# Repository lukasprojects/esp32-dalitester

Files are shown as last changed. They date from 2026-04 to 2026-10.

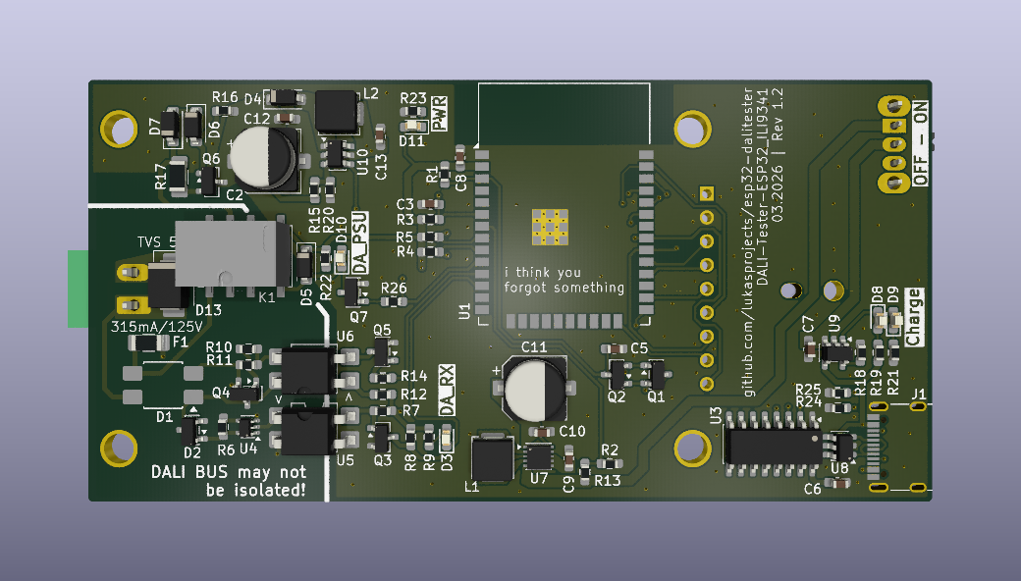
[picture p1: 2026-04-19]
ESP32_DALITester_front.png

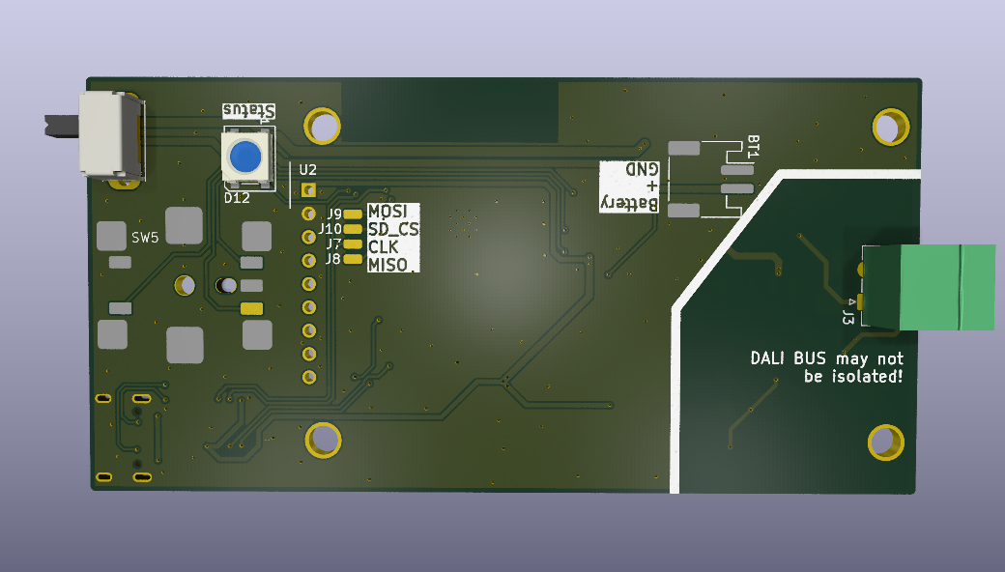
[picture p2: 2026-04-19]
ESP32_DALITester_back.png

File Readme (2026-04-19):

# ESP32 DALI Tester (TFT UI + Encoder + Bus Monitor)

A compact, hands-on DALI tool built around an ESP32 with a 2.2" ILI9341 TFT and a rotary encoder. It can send DALI commands, scan devices, commission / change short addresses, 
clone key configuration values, reset device config, and monitor bus traffic.

> Note on provenance:  
> The firmware was created using AI-assisted “vibe coding” (with human iteration and testing).  
> The PCB / hardware wiring & integration were designed and built by hand.
> Current FW version (1.3.8) only allows for DALI1 and a few DALI2 devices (not all sensors are found).
> Please understand that the DALI bus may not be isolated from mains voltage! Do not use the internal power supply if there is allready voltage on the bus!
  If you are using the internal power supply, the DALI bus is not fully isolated! If you use an external supply, the tool is fully isolated.
  The internal power supply should be able to output 150mA, so it is not capable to supply a whole set of 64 devices, i tested it with more than 10 devices.

---

# Features

- TFT UI (ILI9341, 320×240) with header/footer and a scrollable home menu
- Rotary encoder navigation
  - Rotate: navigate lists / change values
  - Short click: select / execute
  - Long press (≥ 700 ms): back
  - Looong press (≥ 8000 ms): easteregg
- DALI Master (via `qqqlab/DALI-Lighting-Interface` / `qqqDALI`)
  - Send common commands (ON/OFF/MIN/MAX)
  - Query status, levels, device type
- Commissioning / addressing
  - Commission all devices
  - Commission unaddressed devices
  - Change short address (initialize → program → verify → terminate)
- Clone configuration
  - Capture and apply: max/min level, power-on level, system-failure level, fade time, fade rate
- Reset config (treats NO_REPLY as success, useful for some drivers)
- Bus Monitor
  - Displays decoded forward frames (address+data) and backward replies
  - Live mode + freeze/scroll mode

---

# Hardware

Core components
- ESP32 (DevKit style)
- ILI9341 2.2" SPI TFT (Adafruit compatible)
- Rotary encoder with push button
- DALI interface hardware (tested with Waveshare Pico-DALI2 and a Tridonic DALI USB “mouse” for generating traffic)
                           
---

# Firmware / Libraries

- Arduino framework on ESP32
- Display:
  - `Adafruit_GFX`
  - `Adafruit_ILI9341`
- DALI:
  - `qqqlab/DALI-Lighting-Interface` (`qqqDALI`)

The DALI timing is driven by a periodic ESP32 hardware timer ISR calling `dali.timer()`.

---

# Building

PlatformIO
1. Install VS Code + PlatformIO
2. Clone this repository
3. Open the folder in VS Code
4. Build and upload:
   - `PlatformIO: Build`
   - `PlatformIO: Upload`
5. Monitor serial output:
   - `PlatformIO: Monitor` (115200 baud)

---

# Project Status

This is an actively iterated DIY project. Expect occasional breaking changes while improving UI, decoding, or hardware compatibility.

---

# Contributing

Issues and PRs are welcome — especially for:
- Additional command decoding in the bus monitor
- Compatibility notes for more DALI interface boards
- UI improvements without increasing RAM usage

---

# License

Please check the repository for the license file(s).  
This project depends on third-party libraries which come with their own licenses (notably the `qqqDALI` library).

---

# Credits

- `qqqlab/DALI-Lighting-Interface` (`qqqDALI`) for the DALI stack
- Adafruit GFX + ILI9341 libraries for the display layer

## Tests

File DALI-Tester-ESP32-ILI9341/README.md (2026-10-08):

# DALI Tester - ESP32 + ILI9341

Ein DALI (Digital Addressable Lighting Interface) Tester mit ESP32 Mikrocontroller, ILI9341 TFT-Display und Rotary Encoder Bedienung.

---

> **🤖 AI-Assistent:** Diese README.md sowie [TODO.md](TODO.md) sind bei jeder Änderung aktuell zu halten!
> Siehe TODO.md für detaillierte Anweisungen.

---

## Projektübersicht

| Eigenschaft | Wert |
|---|---|
| **Plattform** | ESP32 (espressif32) |
| **Framework** | Arduino |
| **Display** | ILI9341 2.8" SPI TFT (320x240) |
| **Eingabe** | Rotary Encoder mit Taster |
| **DALI Library** | qqqDALI (qqqlab) |
| **Version** | 1.4.0 |
| **Letztes Update** | 2026-07-30 |

## Funktionen

### Implementierte Features

| Feature | Status | Beschreibung |
|---|---|---|
| Home Menu | ✅ | Scrollbares Kachel-Menü (3×4 Grid) mit Icons |
| Scan Devices | ✅ | Scannt Control Gear (SA 0-63), DALI-2 Control Devices und unadressierte Geräte |
| Device Info | ✅ | Kontextmenü mit Seriennummer, Typ und Locate |
| Device Parameters | ✅ | Alle Parameter anzeigen/bearbeiten inkl. Gruppen & Szenen |
| Broadcast Control | ✅ | Drehen=Dimmen, Click=AN/AUS |
| Address Device | ✅ | Address ALL, Unaddressed, Change Address |
| Clone Config | ✅ | Liest/schreibt Gerätekonfiguration |
| Reset Device | ✅ | Setzt Einzelgerät zurück (DALI RESET) |
| DALI PSU | ✅ | EXT/INT Umschaltung mit Confirm-Popup |
| Send CMD | ✅ | Broadcast/Group/Short + ON/OFF/MIN/MAX |
| Locate | ✅ | Zyklisches MIN/MAX Blinken |
| Bus Monitor | ✅ | Frame-Anzeige mit Freeze/Live Mode, DALI-2 Device-Cmd Erkennung |
| SD Browser | ✅ | Ordnerstruktur der SD-Karte direkt auf dem TFT durchblättern |
| WAGO Viewer | ✅ | Read-only Anzeige von WAGO-Projekten aus entpackten XML-Dateien |

### UI Features

- **Header**: Titel + Status-Badges (BUS Status, PSU Mode)
- **Footer**: Kontext-sensitiver Hint-Text
- **Navigation**: Rotate=Auswahl, Click=Bestätigen, Long Press (≥700ms)=Zurück

## Hardware-Konfiguration

### Pin-Belegung (Hardware Rev1.1)

| Funktion | Pin | Beschreibung |
|---|-----|---|
| **TFT Display** | | |
| TFT_CS | GPIO 5 | Chip Select |
| TFT_DC | GPIO 4 | Data/Command |
| TFT_RST | GPIO 17 | Reset (-1 wenn an EN) |
| TFT_MOSI | GPIO 23 | SPI MOSI (VSPI) |
| TFT_SCLK | GPIO 18 | SPI Clock (VSPI) |
| TFT_MISO | GPIO 19 | SPI MISO (optional) |
| TFT_LED | GPIO 2 | Backlight (HIGH = an) |
| **Encoder** | | |
| ENC_A | GPIO 33 | Encoder Signal A |
| ENC_B | GPIO 32 | Encoder Signal B |
| ENC_BTN | GPIO 34 | Button (active LOW, ext. Pullup) |
| **DALI Interface** | | |
| DALI_TX | GPIO 26 | Transmit (Open-Drain) |
| DALI_RX | GPIO 27 | Receive |
| DALI_PSU_EN | GPIO 25 | PSU Enable |
| **Battery Monitor** | | |
| BATTERY_ADC | GPIO 35 | Akkuspannung via Spannungsteiler |
| **SD Card** | | |
| SD_CS | GPIO 13 | Chip Select der SD-Karte (SPI shared mit TFT) |

### Konfigurierbare Einstellungen

Alle Pins und Settings können in `include/config.h` angepasst werden:

```cpp
// TX/RX Invertierung (abhängig von Hardware-Interface)
#define DALI_TX_INVERT  true    // true für typische Opto/Transistor-Schaltung
#define DALI_RX_INVERT  false   // true wenn RX-Schaltung invertiert

// PSU Enable Logik
#define PSU_EN_ACTIVE_HIGH  true  // HIGH = PSU aktiv

// Encoder Richtung und Steps
#define ENCODER_DIR     -1      // +1 oder -1 für Umkehrung
#define ENC_STEP_DIV    4       // Steps pro Rastung

// SD-Karte (shared SPI mit TFT)
#define SD_CS           13
```

## SD Browser und WAGO Viewer

- **SD Browser**: zeigt die Ordnerstruktur der eingelegten SD-Karte direkt im Gerät an.
- **WAGO Viewer**: sucht auf der SD-Karte nach WAGO-Projekten und zeigt die projektierten XML-Dateien read-only an.
- **Wichtig**: Für die eigentliche Projektansicht muss eine `.wdc2s` Datei am PC entpackt und als XML-Ordner auf die SD-Karte kopiert werden. Gepackte `.wdc2s` Dateien werden erkannt, aber aktuell nur mit einem Hinweis angezeigt.

## Projektstruktur

```
DALI-Tester-ESP32-ILI9341/
├── platformio.ini          # PlatformIO Konfiguration
├── README.md               # Diese Datei
├── include/
│   ├── config.h            # Pin-Definitionen und Settings
│   ├── dali/
│   │   └── dali_interface.h    # DALI API Header
│   └── ui/
│       ├── ui.h            # UI Core Header
│       └── screens.h       # Screen Handler Header
├── src/
│   ├── main.cpp            # Hauptprogramm
│   ├── dali/
│   │   └── dali_interface.cpp  # DALI Implementierung
│   └── ui/
│       ├── ui.cpp          # UI Core Implementierung
│       └── screens.cpp     # Alle Screen Handler
├── lib/                    # (leer - Libraries via lib_deps)
└── test/                   # (leer - für Unit Tests)
```

## Build & Flash Anleitung

### Voraussetzungen

- [PlatformIO](https://platformio.org/) (VS Code Extension oder CLI)
- USB-Kabel für ESP32

### Build

```bash
# Projekt bauen
pio run

# Oder mit Verbose Output
pio run -v
```

### Flash

```bash
# Firmware hochladen
pio run -t upload

# Mit spezifischem Port
pio run -t upload --upload-port COM3
```

### Serial Monitor

```bash
# Monitor starten (115200 baud)
pio device monitor -b 115200

# Build + Upload + Monitor
pio run -t upload -t monitor
```

## Dependencies

Die Libraries werden automatisch über `lib_deps` in `platformio.ini` installiert:

```ini
lib_deps = 
    adafruit/Adafruit GFX Library@^1.11.9
    adafruit/Adafruit ILI9341@^1.6.0
    adafruit/Adafruit BusIO@^1.14.5
    https://github.com/qqqlab/DALI-Lighting-Interface.git
```

## DALI Interface Hardware

### Typischer Schaltkreis

```
ESP32 DALI_TX (GPIO26) ──[1k]──┬── Optokoppler/Transistor ── DALI Bus +
                               │
                              GND

DALI Bus + ── Optokoppler RX ──┬── DALI_RX (GPIO27)
                               │
                             [10k]
                               │
                              3.3V
```

**Hinweise:**
- TX Pin als Open-Drain konfiguriert
- TX_INVERT=true für typische Transistor/Opto-Schaltungen
- RX mit Pullup (intern oder extern)
- DALI Bus benötigt 16V DC Versorgung

## Bus Monitor

Der Bus Monitor nutzt **ausschließlich** `dali.rx()` aus der qqqDALI Library - **kein RMT** (wegen Manchester Alignment Problemen).

### Frame-Dekodierung

| Frame Typ | Format | Beispiel |
|---|---|---|
| Broadcast Cmd | `BC <CMD>` | `BC MAX` |
| Group Cmd | `G<n> <CMD>` | `G5 OFF` |
| Short Addr Cmd | `SA<n> <CMD>` | `SA12 Q_STATUS` |
| Direct Arc | `SA<n> ARC <val>` | `SA0 ARC 128` |
| Reply | `REPLY 0x<hex> (<dec>)` | `REPLY 0x80 (128)` |

## Bedienung

### Encoder

| Aktion | Funktion |
|---|---|
| Drehen | Navigation / Wert ändern |
| Kurz drücken (<700ms) | Select / Next / Execute |
| Lang drücken (≥700ms) | Zurück / Abbrechen |

### Status Badges

| Badge | Bedeutung |
|---|---|
| IDLE | Keine Aktivität |
| ACT | RX Aktivität erkannt |
| SEND | Kommando wird gesendet |
| OK | Letztes Kommando erfolgreich |
| NO RPLY | Keine Antwort erhalten |
| BUS ERR | DALI Bus Fehler |
| FAILED | Kommando fehlgeschlagen |
| EXT | Externe PSU |
| INT | Interne PSU aktiv |

## Changelog

### Version 1.4.0 (2026-07-30)

- ✅ **SD Browser**: Neuer Menüpunkt zum Durchblättern der SD-Karten-Ordnerstruktur direkt auf dem TFT
- ✅ **WAGO Viewer**: Neuer Menüpunkt für read-only Anzeige von WAGO-Projekten auf Basis entpackter `solution.xml` / `module_*.xml` Dateien
- ✅ **SD-Konfiguration**: Neue `SD_CS` / `SD_SPI_*` Defines in `include/config.h` für anpassbare Verdrahtung

### Version 1.3.8 (2026-04-12)

- ✅ **Easter Egg**: Pong-Spiel! Im Hauptmenü Encoder 8 Sekunden gedrückt halten. Wand links, Paddle rechts per Encoder. Long Press zum Verlassen.

### Version 1.3.7 (2026-04-12)

- ✅ **Home-Menü Flicker-Fix**: Partial Redraw zeichnet nur geänderte Tiles neu statt gesamten Content-Bereich
- ✅ **Header-Badges vergrößert**: Badges 4px höher und breiter für bessere Lesbarkeit
- ✅ **Batterie-Anzeige Fix**: Spannung wird jetzt sofort beim Start korrekt angezeigt (war 0.0V)

### Version 1.3.6 (2026-04-08)

- ✅ **Hardware Rev 1.1**: Pin-Belegung aktualisiert (TFT_CS=GPIO5, TFT_DC=GPIO4, TFT_RST=GPIO17)
- ✅ **LCD Backlight**: Neuer TFT_LED Pin (GPIO 2) für Hintergrundbeleuchtung, dauerhaft HIGH
- ✅ **Build-Fix**: `-Wno-error=return-type` Flag für Kompatibilität mit aktualisierter ESP32-Plattform

### Version 1.3.5 (2026-03-25)

- ✅ **GOTO SCENE im Send CMD**: Szenen 0-15 können jetzt direkt über Send CMD aufgerufen werden (neues Kommando "SCENE" mit Szenen-Nummer Auswahl)
- ✅ **HW-Version & Credits im Home-Screen**: Footer zeigt jetzt zweizeilig FW-Version (by Claude Code Opus 4.6) und HW-Version (by Lukas Meissner)
- ✅ **HW_VERSION Define**: Zentrale HW-Versionsverwaltung in config.h

### Version 1.3.4 (2026-03-24)

- ✅ **Bugfix Bus Monitor Live-Ansicht**: Ring-Buffer verwendete nur Count für Änderungserkennung — bei vollem Buffer (80 Einträge) wurde kein Update mehr erkannt. Jetzt mit Generation-Counter der bei jedem neuen Frame zählt

### Version 1.3.3 (2026-03-22)

- ✅ **Bugfix Reset Adresse löschen**: SET SHORT ADDRESS wird jetzt mit REPEAT-Flag (doppelt) gesendet wie vom DALI-Standard gefordert
- ✅ **Bugfix DALI PSU Navigation**: Popup-Rückkehr stellt previousScreen korrekt wieder her, kein doppeltes Zurück mehr nötig
- ✅ **FW-Version im Home-Screen**: Footer zeigt Firmware-Version und "powered by Claude Opus"
- ✅ **FW_VERSION Define**: Zentrale Versionsverwaltung in config.h

### Version 1.3.2 (2026-03-22)

- ✅ **Scrollbares Kachel-Menü**: 3×4 Grid mit größeren Kacheln (102×88px), scrollbar per Encoder
- ✅ **Pixel-Art Icons**: 10 individuelle Icons für jedes Menü-Item (Lupe, Zahnrad, Blitz, Fadenkreuz, etc.)
- ✅ **Visuelle Verbesserung**: Ausgewählte Kachel in Cyan, unselektierte mit dezenter Umrandung und Icon

### Version 1.3.1 (2026-03-21)

- ✅ **Home Menu Kachel-Design**: 3×4 Grid mit abgerundeten Kacheln statt scrollbare Liste
- ✅ **Tile Labels**: Kompakte zweizeilige Beschriftung pro Kachel
- ✅ **Visuelle Verbesserung**: Ausgewählte Kachel in Cyan, unselektierte mit dezenter Umrandung

### Version 1.3.0 (2026-03-20)

- ✅ **DALI-2 Control Device Scan**: Sensoren, Taster und andere Control Devices werden per S=0 Adressierung erkannt
- ✅ **Unified Scan List**: Control Gear (weiss), Control Devices (grün) und Unadressierte (orange) in einer Liste
- ✅ **DALI-2 Device Type Namen**: Neue Typnamen für Device Types 128-140 (Switch, OccSensor, Gateway, etc.)
- ✅ **Bus Monitor DALI-2**: S=0 Frames mit Command-Werten >=0x90 werden als Device-Commands dekodiert

### Version 1.2.3 (2026-03-19)

- ✅ **Bugfix Adresse löschen**: INITIALISE/TERMINATE Sequenz hinzugefügt - SET SHORT ADDRESS erfordert INITIALISE-Status laut DALI-Standard
- ✅ **Bugfix Navigation**: Zurück von Detailansicht kehrt jetzt zur Scan-Liste zurück statt zum Home-Menü

### Version 1.2.2 (2026-03-20)

- ✅ **Scan Devices: Unified List**: Adressierte und unadressierte Geräte werden jetzt in einer gemeinsamen Liste angezeigt
- ✅ **Unadressierte Zählung**: `daliCountUnaddressed()` zählt unadressierte Geräte per Binary-Search (ohne Adressvergabe)
- ✅ **Visuelle Unterscheidung**: Unadressierte Geräte in Orange, adressierte in Weiß

### Version 1.2.1 (2026-03-19)

- ✅ **Bugfix Clone/Write Config**: Robusteres Schreiben mit Verifikation, damit fehlerhafte Write-Vorgaenge nicht mehr als OK angezeigt werden
- ✅ **Bugfix Fade Query**: Korrekte Auswertung von Fade Time/Fade Rate aus dem gemeinsamen DALI-Reply-Byte
- ✅ **Bugfix Reset Device**: Reset + optionales Adress-Loeschen mit korrekter DALI-Sequenz und Rueckpruefung
- ✅ **Hardware Rev1.0 Doku**: Pin-Tabelle in README an `include/config.h` angepasst

### Version 1.2.0 (2026-03-03)

- ✅ **Device Parameters**: Neues Menü zur Anzeige/Bearbeitung aller Geräteparameter
  - Max/Min Level, Power On Level, System Failure Level
  - Fade Time, Fade Rate
  - Gruppenzuweisungen (0-15) anzeigen und ändern
  - Szenen-Level (0-15) anzeigen und setzen
- ✅ **Bugfix Broadcast Control**: Display-Refresh beim Dimmen korrigiert
- ✅ **Bugfix Serial Number**: Bessere Anzeige bei nicht zugewiesenen Seriennummern ("Not Assigned")

### Version 1.1.0 (2026-02-24)

- ✅ **Broadcast Control**: Neues Menü zum direkten Dimmen aller Leuchten (Drehen=Dimmen, Click=AN/AUS)
- ✅ **Device Info Kontextmenü**: Klick auf gescannte Geräte zeigt Details (Seriennummer, Typ, Status)
- ✅ **Locate im Scan**: Locate-Funktion direkt aus dem Device Info Screen (2s Intervall)
- ✅ **Device Type Namen**: Anzeige von Typnamen statt Nummern (Fluorescent, LED, etc.)
- ✅ **Pin-Belegung aktualisiert**: TFT_CS=GPIO2, TFT_DC=GPIO17 für PCB v1

### Version 1.0.0 (2026-02-22)

- ✅ Initiale Implementierung
- ✅ Alle 8 Hauptmenü-Funktionen
- ✅ Encoder-Steuerung mit Debouncing
- ✅ DALI Master via qqqDALI
- ✅ Bus Monitor mit Ring-Buffer (80 Einträge)
- ✅ Scrollbare Listen
- ✅ Confirm-Popup für PSU

## Bekannte Einschränkungen

1. **Bus Monitor RX**: Erkennt aktuell nur 8-Bit Backward Frames vollständig. Forward Frame Dekodierung für passives Mithören erfordert erweiterte qqqDALI Integration.

2. **Commissioning**: Nutzt die qqqDALI `commission()` Funktion. Komplexe Szenarien (Multi-Device, Conflicts) müssen ggf. manuell behandelt werden.

3. **Display Refresh**: Bei schnellen Änderungen kann leichtes Flackern auftreten.

4. **WAGO Viewer**: Die Projektanzeige ist aktuell read-only und nutzt eine heuristische XML-Auswertung. Für volle Bearbeitung/Speicherung fehlt noch der spätere Import/Export-Schritt.

## Assumptions (Designentscheidungen)

1. **Timer**: ESP32 Hardware Timer 0 mit 80 Prescaler (1µs Auflösung) für DALI Timing (104µs Interrupt)

2. **Encoder**: Typischer Quadrature-Encoder mit 4 Steps pro Detent

3. **DALI Timing**: Standard Manchester-Encoding mit qqqDALI Library

4. **Ring Buffer**: Statische Allokation (80 Einträge) ohne dynamischen Speicher

5. **Screen State**: Separate State-Structs pro Screen (statisch alloziert)

## Lizenz

Dieses Projekt verwendet die qqqDALI Library von qqqlab (MIT License).

---

*Dokumentation zuletzt aktualisiert: 2026-07-30*

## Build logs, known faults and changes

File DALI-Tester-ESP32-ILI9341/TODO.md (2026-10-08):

# DALI Tester - Feature & Aufgabenliste

> **Letzte Aktualisierung:** 2026-07-30

---

## 🤖 AI-Assistent Hinweis

> **WICHTIG FÜR JEDE NEUE SESSION:**
> 
> 1. **TODO.md** - Diese Datei bei jeder Änderung aktualisieren:
>    - Erledigte Features mit `[x]` markieren
>    - Neue Features/Bugs hinzufügen
>    - "Nächste Schritte" Prioritäten anpassen
>    - "Letzte Aktualisierung" Datum aktualisieren
>
> 2. **README.md** - Bei relevanten Änderungen aktualisieren:
>    - Feature-Status-Tabelle pflegen
>    - Changelog erweitern bei neuen Versionen
>    - "Bekannte Einschränkungen" aktuell halten
>    - "Letztes Update" Datum im Header aktualisieren
>
> 3. **Projektstatus** - Immer den aktuellen Stand dokumentieren:
>    - Was funktioniert?
>    - Was ist in Arbeit?
>    - Was sind bekannte Probleme?
>
> So weiß jeder Nutzer (und jede AI-Session) sofort, wie der Projektstatus ist.
>
> 4. **Build & Test** - PlatformIO Befehle (PowerShell):
>    ```powershell
>    # Build
>    & "$env:USERPROFILE\.platformio\penv\Scripts\platformio.exe" run
>    
>    # Upload
>    & "$env:USERPROFILE\.platformio\penv\Scripts\platformio.exe" run --target upload
>    
>    # Serial Monitor
>    & "$env:USERPROFILE\.platformio\penv\Scripts\platformio.exe" device monitor -b 115200
>    ```
>    **Hinweis:** `pio` und `python -m platformio` funktionieren NICHT in dieser Umgebung!

---

## Legende

- ✅ Abgeschlossen
- 🔄 In Bearbeitung
- ⏳ Geplant (hohe Priorität)
- 💡 Idee / Nice-to-have
- ❌ Blockiert / Problem

---

## ⚠️ Erinnerung: FW-Version

> **Bei JEDEM Release:** `FW_VERSION` in `include/config.h` hochzählen!
> Auch `README.md` Versionstabelle und Changelog aktualisieren.

---

## Hauptfunktionen

### Home Menu
- [x] Scrollbares Kachel-Menü (3×4 Grid) mit Icons und abgerundeten Kacheln
- [x] 10 Bitmap-Icons (38×38px, 1-bit monochrom via drawBitmap)
- [x] Header mit Titel und Status-Badges
- [x] Footer mit kontext-sensitiven Hints
- [x] Menüpunkt für SD-Karten-Browser
- [x] Menüpunkt für WAGO-Projektanzeige (read-only)

### SD / Projektdateien
- [x] SD-Karten-Ordnerstruktur anzeigen
- [x] WAGO-Projekte auf SD erkennen (`solution.xml`, `module_*.xml`)
- [x] Read-only Anzeige von WAGO-Projekten
- [ ] WAGO-Projekte bearbeiten und speichern
- [ ] Native `.wdc2s` ZIP-Dateien direkt auf dem ESP32 lesen

### Device Parameters
- [x] Geräteparameter auslesen (Levels, Fade, etc.)
- [x] Gruppenzuweisungen anzeigen (bitmask)
- [x] Szenen-Level anzeigen (0-15)
- [x] Parameter bearbeiten und speichern
- [x] Gruppen hinzufügen/entfernen
- [x] Szenen-Level setzen

### Scan Devices
- [x] Scan Short Addresses 0-63
- [x] Device Type Anzeige
- [x] Scrollbare Ergebnisliste
- [x] Device Type Namen statt Nummern anzeigen
- [x] Zusätzliche Geräteinformationen (Actual Level, Status)
- [x] Geräte-Kontextmenü mit Seriennummer und Locate
- [x] Erkennung von nicht-adressierten Geräten auf dem Bus
- [x] Unadressierte Geräte in der Scan-Liste anzeigen (unified list)
- [x] DALI-2 Control Devices erkennen und in Scan-Liste anzeigen
- [x] Busspannungs-Erkennung vor Scan (Error Handling bei fehlendem Bus)

### Broadcast Control
- [x] Click = AN/AUS Toggle
- [x] Drehen = Dimmen (Direct Arc Power)
- [x] Visueller Level-Balken

### Address Device
- [x] Address ALL (alle Geräte neu adressieren)
- [x] Address Unaddressed (nur nicht-adressierte)
- [x] Change Address (einzelne Adresse ändern)
- [ ] Fortschrittsanzeige während Commissioning
- [ ] Konflikt-Erkennung bei doppelten Adressen

### Clone Config
- [x] Lesen der Gerätekonfiguration
- [x] Schreiben auf anderes Gerät
- [x] Source/Target Auswahl
- [ ] Config-Preview vor dem Schreiben
- [ ] Mehrere Geräte gleichzeitig beschreiben

### Reset Device
- [x] DALI RESET Befehl an einzelnes Gerät
- [ ] Reset ALL (Broadcast Reset)
- [ ] Reset-Bestätigung mit Abfrage

### DALI PSU
- [x] EXT/INT Umschaltung
- [x] Confirm-Popup vor Umschaltung
- [ ] PSU Status-Überwachung (Überstrom, etc.)

### Send CMD
- [x] Target-Typ: Broadcast / Group / Short Address
- [x] Kommandos: ON / OFF / MIN / MAX
- [ ] Erweiterte Kommandos (UP, DOWN, STEP_UP, STEP_DOWN)
- [x] Scene-Befehle (GOTO SCENE 0-15)
- [ ] Direct Arc Level senden (0-254)
- [ ] Query-Kommandos mit Antwort-Anzeige

### Locate
- [x] Zyklisches MIN/MAX Blinken
- [x] Einstellbares Intervall (200-3000ms)
- [x] Start/Stop Steuerung
- [ ] Locate für Gruppen
- [ ] Locate mit Fade statt hartem Umschalten

### Bus Monitor
- [x] Live Frame-Anzeige
- [x] Freeze/Live Mode Toggle
- [x] Ring-Buffer (80 Einträge)
- [x] Frame-Dekodierung (BC, Group, Short)
- [x] DALI-2 Event Frames (24-bit) Dekodierung
- [ ] Frame-Filter (nur bestimmte Adressen)
- [ ] Export/Log-Funktion
- [ ] Timestamp-Anzeige (relativ oder absolut)

---

## UI / UX

### Display
- [x] ILI9341 320x240 TFT Support
- [x] Farbschema (Dark Theme)
- [x] LCD Backlight Steuerung (TFT_LED Pin)
- [ ] Helligkeit einstellbar
- [ ] Display-Timeout / Screensaver
- [ ] Alternative Farbschemata

### Navigation
- [x] Rotary Encoder mit Taster
- [x] Long Press (≥700ms) für Zurück
- [x] Debouncing
- [ ] Beschleunigtes Scrollen bei schnellem Drehen
- [ ] Haptic Feedback (optional, falls Hardware vorhanden)

### Status-Anzeige
- [x] BUS Status Badge (IDLE, ACT, SEND, OK, etc.)
- [x] PSU Mode Badge (EXT/INT)
- [x] Batterie-Anzeige im Header (Prozent + Farbe)
- [ ] Verbindungsstatus-Indikator
- [ ] Fehler-Log / History

---

## DALI Protokoll

### Basis-Kommandos
- [x] Direct Arc Power Control
- [x] OFF, RECALL MAX, RECALL MIN
- [x] Query Status, Query Actual Level
- [ ] UP, DOWN, STEP UP, STEP DOWN
- [ ] ON AND STEP UP, STEP DOWN AND OFF

### Konfiguration
- [x] Query/Set Max Level
- [x] Query/Set Min Level
- [x] Query/Set Power On Level
- [x] Query/Set System Failure Level
- [x] Query/Set Fade Time/Rate
- [ ] Query/Set Extended Fade Time
- [ ] Scene Level Konfiguration (0-15)

### Gruppen
- [x] Gruppe zuweisen (ADD TO GROUP) via Device Parameters
- [x] Gruppe entfernen (REMOVE FROM GROUP) via Device Parameters
- [x] Gruppenübersicht anzeigen

### Erweiterte Features
- [ ] DALI-2 Control Device Discovery (Sensoren, Taster)
- [x] DALI-2 Device Type Unterstützung (Control Device Scan + Typ-Namen)
- [ ] Memory Bank Lesen
- [ ] Colour Control (DT8)
- [x] Event-basierte Anzeige (Bus Monitor)

---

## Hardware / System

### ESP32
- [x] Hardware Timer für DALI Timing (104µs)
- [x] Open-Drain TX Pin
- [ ] Deep Sleep Mode bei Inaktivität
- [ ] OTA Updates
- [ ] WiFi-Interface (optional)

### DALI Interface
- [x] TX/RX Invertierung konfigurierbar
- [x] PSU Enable Steuerung
- [ ] Bus-Spannungsüberwachung
- [ ] Kurzschluss-Erkennung

---

## Bekannte Probleme

- [ ] **Bus Monitor**: Forward Frames (16-bit) werden nicht vollständig dekodiert bei passivem Mithören
- [ ] **Display Flackern**: Bei schnellen Änderungen kann leichtes Flackern auftreten
- [ ] **Commissioning**: Komplexe Multi-Device Szenarien erfordern manuelle Behandlung

---

## Nächste Schritte (Priorisiert)

1. ✅ Forward Frame Dekodierung im Bus Monitor (erledigt inkl. DALI-2 Events)
2. ⏳ Erweiterte Send CMD Optionen (UP, DOWN, Direct Arc)
3. ✅ Device Type Namen statt Nummern (erledigt)
4. ⏳ Query-Kommandos mit Antwort-Anzeige
5. ✅ Gruppen-Management (erledigt via Device Parameters)
6. ✅ Scene-Konfiguration (erledigt via Device Parameters)
7. ✅ Erkennung nicht-adressierter Geräte (erledigt im Scan)
8. ✅ DALI-2 Control Device Scan (Sensoren, Taster etc.)
9. 💡 DALI-2 Control Device Discovery (erweitert: Instanzen, Memory Banks)
10. ⏳ WAGO-Projekte bearbeiten und wieder speichern
11. 💡 WiFi-Interface für Remote-Steuerung

---

## Notizen

- 2026-03-19: Clone/Config-Write und Reset-Sequenzen robuster gemacht (inkl. Verifikation und korrektem Adress-Loeschen via SET SHORT ADDRESS + DTR=255).
- 2026-03-19: README Pin-Mapping auf aktuelle Hardware Rev1.0 aus `include/config.h` abgeglichen.
- 2026-03-20: Scan Devices zeigt jetzt adressierte UND unadressierte Geräte in einer gemeinsamen Liste (v1.2.2).
- 2026-03-19: Adress-Löschung korrigiert (INITIALISE fehlte), Navigation von Detailansicht geht zurück zur Scan-Liste (v1.2.3).
- 2026-04-12: Pong Easter Egg hinzugefügt (8s Hold im Home-Menü) (v1.3.8).
- 2026-07-30: SD Browser und read-only WAGO Viewer hinzugefügt. WAGO-Projekte werden auf SD per `solution.xml` / `module_*.xml` erkannt; gepackte `.wdc2s` Dateien zeigen vorerst nur einen Entpack-Hinweis (v1.4.0).
- 2026-04-12: Home-Menü Partial Redraw (nur geänderte Tiles), Header-Badges vergrößert (+4px), Batterie-Anzeige beim Start repariert (v1.3.7).
- 2026-04-08: Hardware Rev 1.1 - Pin-Belegung aktualisiert (TFT_CS=5, TFT_DC=4, TFT_RST=17), LCD Backlight Pin (TFT_LED=GPIO2) hinzugefügt.
- 2026-03-24: Bus Monitor Live-Ansicht repariert - Ring-Buffer Count blieb bei 80 stehen, Generation-Counter eingeführt (v1.3.4).
- 2026-03-22: Reset-Adressloeschung repariert (SET SHORT ADDRESS ohne REPEAT Flag war Ursache), PSU-Popup Navigation repariert, FW-Version im Home-Footer (v1.3.3).

<!-- 
Platz für eigene Notizen, Ideen, etc.
-->

---

*Diese Datei wird laufend aktualisiert. Features können nach Bedarf umpriorisiert werden.*

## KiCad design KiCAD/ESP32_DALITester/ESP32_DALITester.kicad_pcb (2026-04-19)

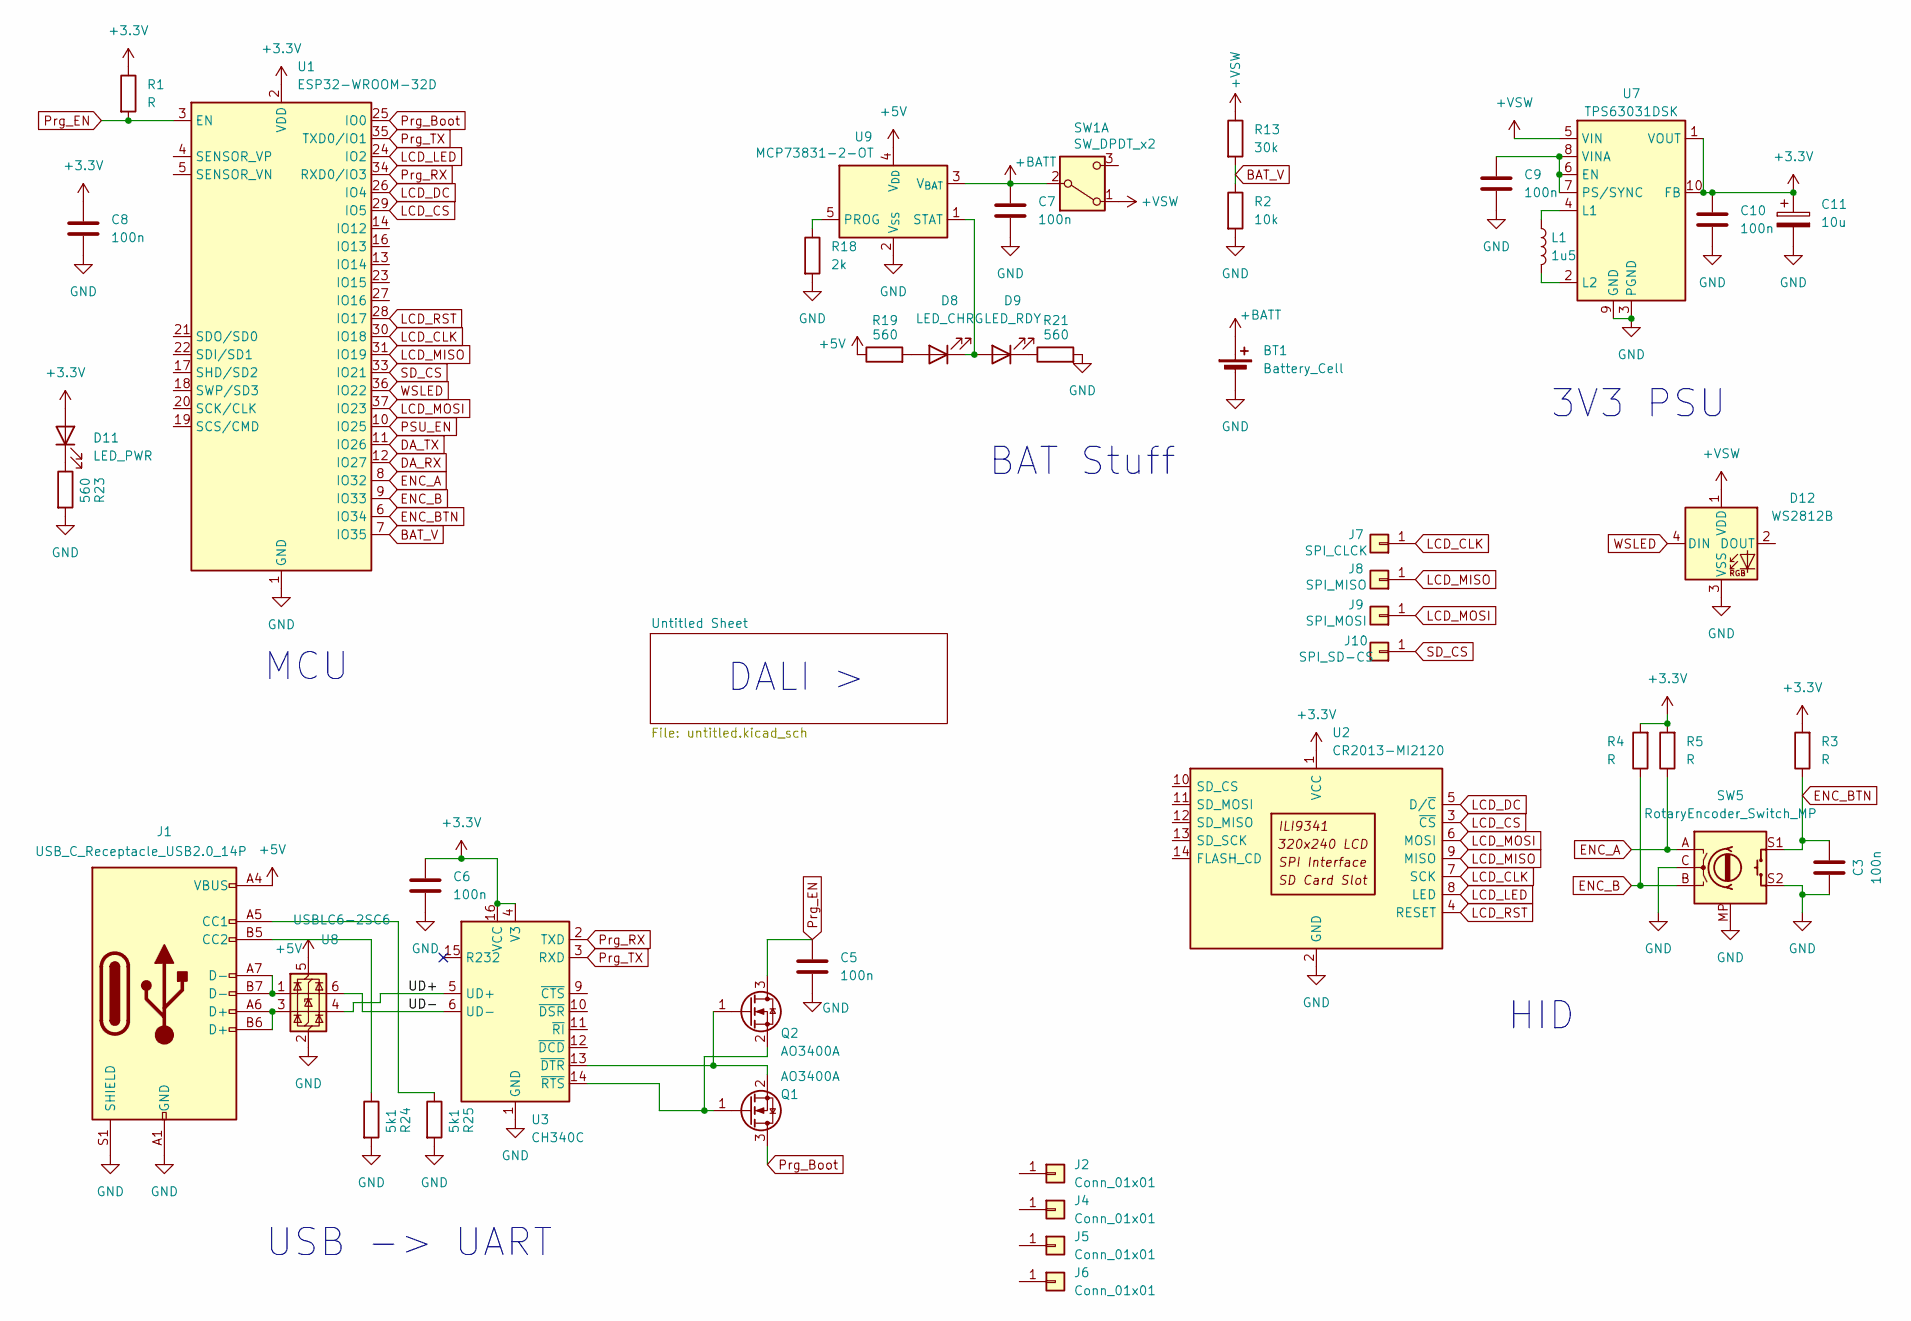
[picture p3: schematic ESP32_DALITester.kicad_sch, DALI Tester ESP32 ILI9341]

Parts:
BT1: Battery_Cell; JST_PH_S2B-PH-SM4-TB_1x02-1MP_P2.00mm_Horizontal
C3, C5, C6, C7, C8, C9, C10: 100n; C_0603_1608Metric_Pad1.08x0.95mm_HandSolder
C11: 10u; CP_Elec_6.3x3
D8: LED_CHRG; LED_0603_1608Metric_Pad1.05x0.95mm_HandSolder
D9: LED_RDY; LED_0603_1608Metric_Pad1.05x0.95mm_HandSolder
D11: LED_PWR; LED_0603_1608Metric_Pad1.05x0.95mm_HandSolder
D12: WS2812B; LED_WS2812B_PLCC4_5.0x5.0mm_P3.2mm
J1: USB_C_Receptacle_USB2.0_14P; USB_C_Receptacle_G-Switch_GT-USB-7010ASV
J2, J4, J5, J6: Conn_01x01; MountingHole_3mm
J7: SPI_CLCK; SolderWirePad_1x01_SMD_1x2mm
J8: SPI_MISO; SolderWirePad_1x01_SMD_1x2mm
J9: SPI_MOSI; SolderWirePad_1x01_SMD_1x2mm
J10: SPI_SD-CS; SolderWirePad_1x01_SMD_1x2mm
L1: 1u5; L_APV_APH0420
Q1, Q2: AO3400A; SOT-23
R1, R3, R4, R5: R; R_0603_1608Metric_Pad0.98x0.95mm_HandSolder
R2: 10k; R_0603_1608Metric_Pad0.98x0.95mm_HandSolder
R13: 30k; R_0603_1608Metric_Pad0.98x0.95mm_HandSolder
R18: 2k; R_0603_1608Metric_Pad0.98x0.95mm_HandSolder
R19, R21, R23: 560; R_0603_1608Metric_Pad0.98x0.95mm_HandSolder
R24, R25: 5k1; R_0603_1608Metric_Pad0.98x0.95mm_HandSolder
SW1: SW_DPDT_x2; SW_Slide_SPDT_Angled_CK_OS102011MA1Q
SW5: RotaryEncoder_Switch_MP; BOURNS PEC11J-9220F-H0015
U1: ESP32-WROOM-32D
U2: CR2013-MI2120
U3: CH340C; SOIC-16_3.9x9.9mm_P1.27mm
U7: TPS63031DSK; WSON-10-1EP_2.5x2.5mm_P0.5mm_EP1.2x2mm
U8: USBLC6-2SC6; SOT-23-6
U9: MCP73831-2-OT; SOT-23-5

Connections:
+3.3V: C6.1, C8.1, C10.1, C11.1, D11.2 (A), R1.1, R3.2, R4.2, R5.2, U1.2 (VDD), U2.1 (VCC), U3.4 (V3), U3.16 (VCC), U7.1 (VOUT), U7.10 (FB); also elsewhere on the board
+5V: J1.A4 (VBUS), J1.A9 (VBUS), J1.B4 (VBUS), J1.B9 (VBUS), R19.1, U8.5 (VBUS), U9.4 (V_{DD})
+BATT: BT1.2 (+), C7.1, SW1.2 (B), U9.3 (V_{BAT})
+VSW: D12.1 (VDD), R13.1, SW1.1 (A), U7.5 (VIN); also elsewhere on the board
/UD+: U3.5 (UD+), U8.4 (I/O2)
/UD-: U3.6 (UD-), U8.6 (I/O1)
BAT_V: R2.1, R13.2, U1.7 (IO35)
DA_RX: U1.12 (IO27); also elsewhere on the board
DA_TX: U1.11 (IO26); also elsewhere on the board
ENC_A: R5.1, SW5.A, U1.8 (IO32)
ENC_B: R4.1, SW5.B, U1.9 (IO33)
ENC_BTN: C3.2, R3.1, SW5.S1, U1.6 (IO34)
GND: BT1.1 (-), C3.1, C5.2, C6.2, C7.2, C8.2, C9.2, C10.2, C11.2, D12.3 (VSS), J1.A1 (GND), J1.A12 (GND), J1.B1 (GND), J1.B12 (GND), J1.S1 (SHIELD), R2.2, R18.2, R21.2, R23.2, R24.2, R25.2, SW5.C, SW5.MP, SW5.S2, U1.1 (GND), U1.15 (GND), U1.38 (GND), U1.39 (GND), U2.2 (GND), U3.1 (GND), U7.3 (PGND), U7.9 (GND), U7.11 (PGND), U8.2 (GND), U9.2 (V_{SS}); also elsewhere on the board
LCD_CLK: J7.1, U1.30 (IO18), U2.7 (SCK)
LCD_CS: U1.29 (IO5), U2.3 (~CS)
LCD_DC: U1.26 (IO4), U2.5 (D/~C)
LCD_LED: U1.24 (IO2), U2.8 (LED)
LCD_MISO: J8.1, U1.31 (IO19), U2.9 (MISO)
LCD_MOSI: J9.1, U1.37 (IO23), U2.6 (MOSI)
LCD_RST: U1.28 (IO17), U2.4 (RESET)
unnamed: D8.2 (A), R19.2
unnamed: D8.1 (K), D9.2 (A), U9.1 (STAT)
unnamed: D9.1 (K), R21.1
unnamed: D11.1 (K), R23.1
unnamed: J1.A5 (CC1), R25.1
unnamed: J1.B5 (CC2), R24.1
unnamed: J1.A6 (D+), J1.B6 (D+), U8.3 (I/O2)
unnamed: J1.A7 (D-), J1.B7 (D-), U8.1 (I/O1)
unnamed: Q1.1 (G), Q2.2 (S), U3.14 (~RTS)
unnamed: Q1.2 (S), Q2.1 (G), U3.13 (~DTR)
unnamed: C9.1, U7.6 (EN), U7.7 (PS/SYNC), U7.8 (VINA)
unnamed: L1.1, U7.4 (L1)
unnamed: L1.2, U7.2 (L2)
unnamed: R18.1, U9.5 (PROG)
PSU_EN: U1.10 (IO25); also elsewhere on the board
Prg_Boot: Q1.3 (D), U1.25 (IO0)
Prg_EN: C5.1, Q2.3 (D), R1.2, U1.3 (EN)
Prg_RX: U1.34 (RXD0/IO3), U3.2 (TXD)
Prg_TX: U1.35 (TXD0/IO1), U3.3 (RXD)
SD_CS: J10.1, U1.33 (IO21)
WSLED: D12.4 (DIN), U1.36 (IO22)

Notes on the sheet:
DALI >
HID
3V3 PSU
BAT Stuff
USB -> UART
MCU

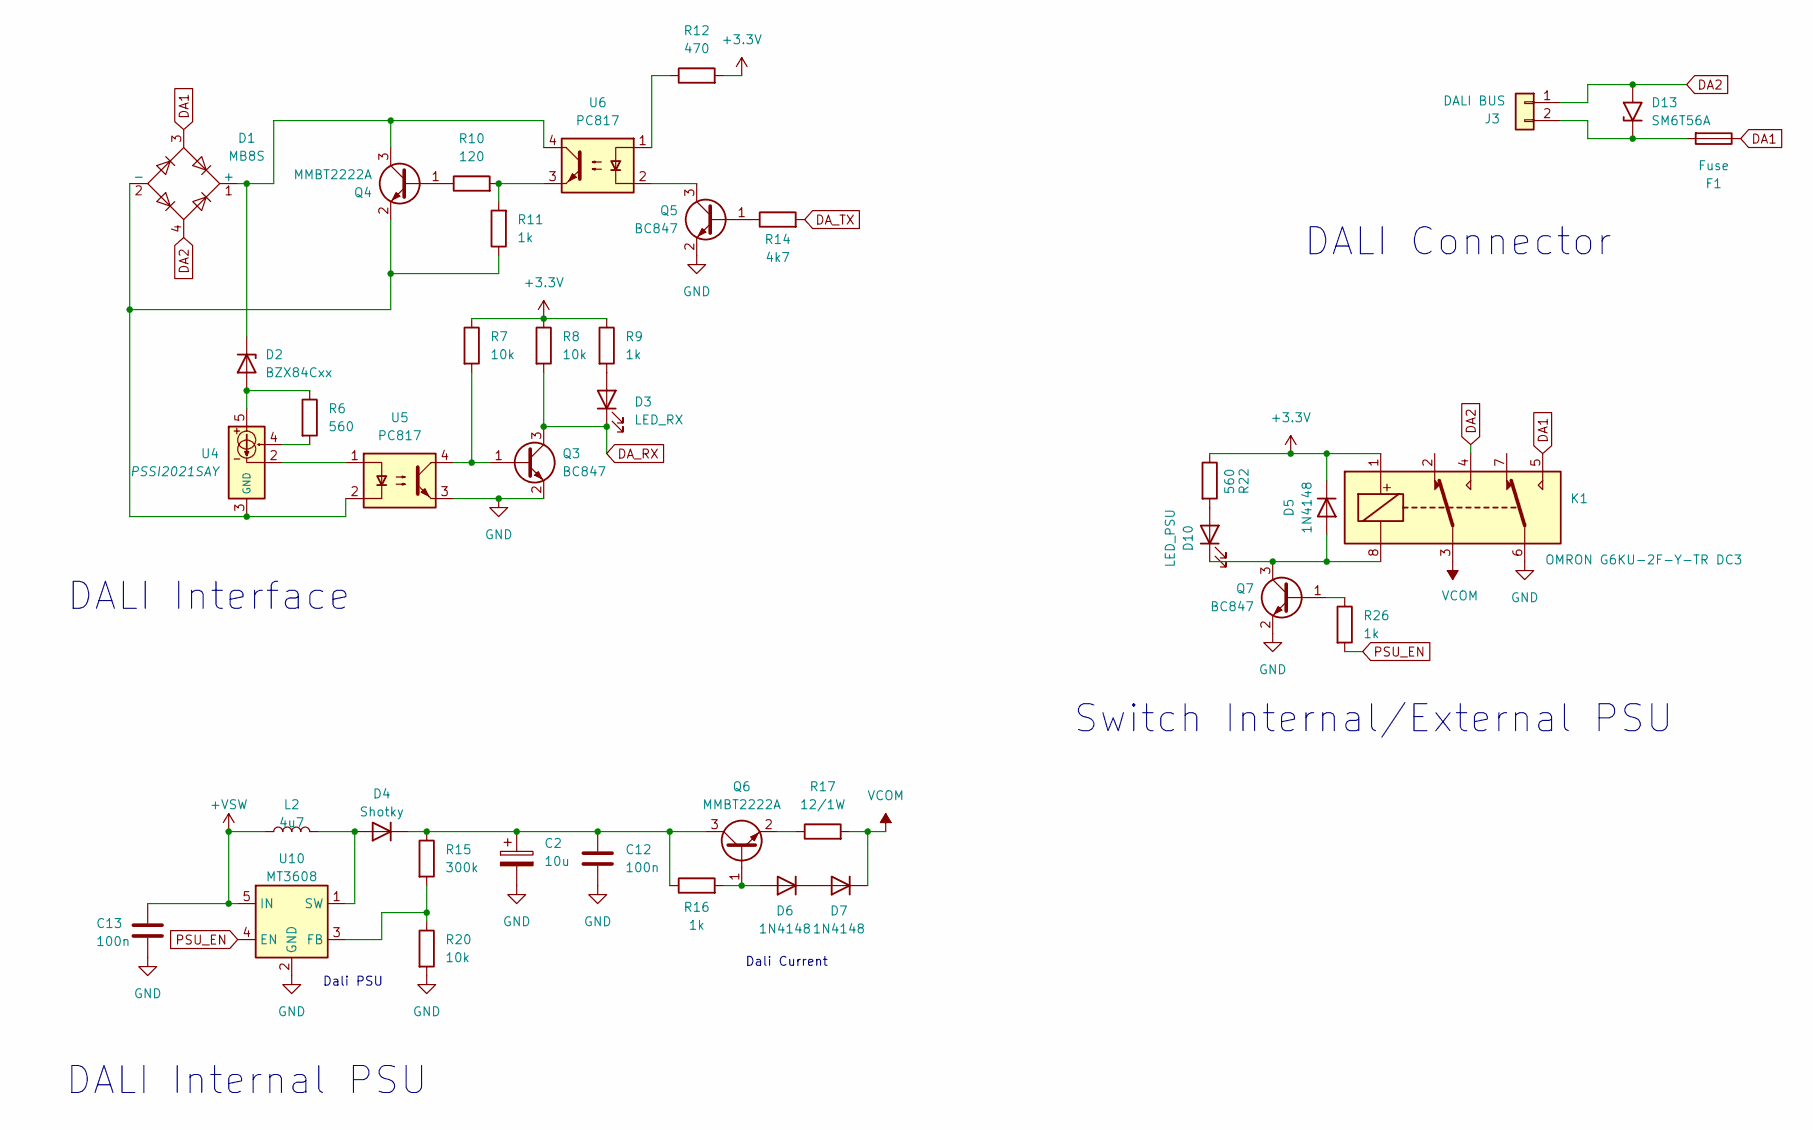
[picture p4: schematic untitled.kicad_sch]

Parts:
C2: 10u; CP_Elec_6.3x3
C12, C13: 100n; C_0603_1608Metric_Pad1.08x0.95mm_HandSolder
D1: MB8S; OnSemi_751EP_SOIC-4_3.9x4.725mm_P2.54mm
D2: BZX84Cxx; SOT-23
D3: LED_RX; LED_0603_1608Metric_Pad1.05x0.95mm_HandSolder
D4: Shotky; D_SOD-123
D5, D6, D7: 1N4148; D_SOD-123
D10: LED_PSU; LED_0603_1608Metric_Pad1.05x0.95mm_HandSolder
D13: SM6T56A; D_SMB
F1: Fuse; Fuse_1206_3216Metric_Pad1.42x1.75mm_HandSolder
J3: DALI BUS; PhoenixContact_MC_1,5_2-G-3.5_1x02_P3.50mm_Horizontal
K1: OMRON G6KU-2F-Y-TR DC3
L2: 4u7; L_APV_APH0420
Q3, Q5, Q7: BC847; SOT-23
Q4, Q6: MMBT2222A; SOT-23
R6, R22: 560; R_0603_1608Metric_Pad0.98x0.95mm_HandSolder
R7, R8, R20: 10k; R_0603_1608Metric_Pad0.98x0.95mm_HandSolder
R9, R11, R16, R26: 1k; R_0603_1608Metric_Pad0.98x0.95mm_HandSolder
R10: 120; R_0603_1608Metric_Pad0.98x0.95mm_HandSolder
R12: 470; R_0603_1608Metric_Pad0.98x0.95mm_HandSolder
R14: 4k7; R_0603_1608Metric_Pad0.98x0.95mm_HandSolder
R15: 300k; R_0603_1608Metric_Pad0.98x0.95mm_HandSolder
R17: 12/1W; R_1206_3216Metric_Pad1.30x1.75mm_HandSolder
U4: PSSI2021SAY; SOT-353_SC-70-5
U5, U6: PC817; SMDIP-4_W7.62mm
U10: MT3608; SOT-23-6

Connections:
+3.3V: D5.1 (K), K1.1, R7.1, R8.1, R9.1, R12.2, R22.1; also elsewhere on the board
+VSW: C13.1, L2.1, U10.5 (IN); also elsewhere on the board
DA1: D1.3, F1.1, K1.5
DA2: D1.4, D13.2 (A2), J3.1, K1.4
DA_RX: D3.1 (K), Q3.3 (C), R8.2; also elsewhere on the board
DA_TX: R14.2; also elsewhere on the board
GND: C2.2, C12.2, C13.2, K1.6, Q3.2 (E), Q5.2 (E), Q7.2 (E), R20.2, U5.3, U10.2 (GND); also elsewhere on the board
unnamed: D1.1 (+), D2.3 (K), Q4.3 (C), U6.4
unnamed: D1.2 (-), Q4.2 (E), R11.1, U4.3 (GND), U5.2
unnamed: D2.1 (A), R6.1, U4.5
unnamed: D3.2 (A), R9.2
unnamed: D4.2 (A), L2.2, U10.1 (SW)
unnamed: C2.1, C12.1, D4.1 (K), Q6.3 (C), R15.1, R16.1
unnamed: D6.2 (A), Q6.1 (B), R16.2
unnamed: D6.1 (K), D7.2 (A)
unnamed: D10.2 (A), R22.2
unnamed: D5.2 (A), D10.1 (K), K1.8, Q7.3 (C)
unnamed: D13.1 (A1), F1.2, J3.2
unnamed: Q3.1 (B), R7.2, U5.4
unnamed: Q4.1 (B), R10.1
unnamed: Q5.1 (B), R14.1
unnamed: Q5.3 (C), U6.2
unnamed: Q6.2 (E), R17.1
unnamed: Q7.1 (B), R26.1
unnamed: R6.2, U4.4
unnamed: R10.2, R11.2, U6.3
unnamed: R12.1, U6.1
unnamed: U4.2, U5.1
unnamed: R15.2, R20.1, U10.3 (FB)
PSU_EN: R26.2, U10.4 (EN); also elsewhere on the board
VCOM: D7.1 (K), K1.3, R17.2

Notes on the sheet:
Dali Current
DALI Connector
DALI Interface
DALI Internal PSU
Switch Internal/External PSU
Dali PSU

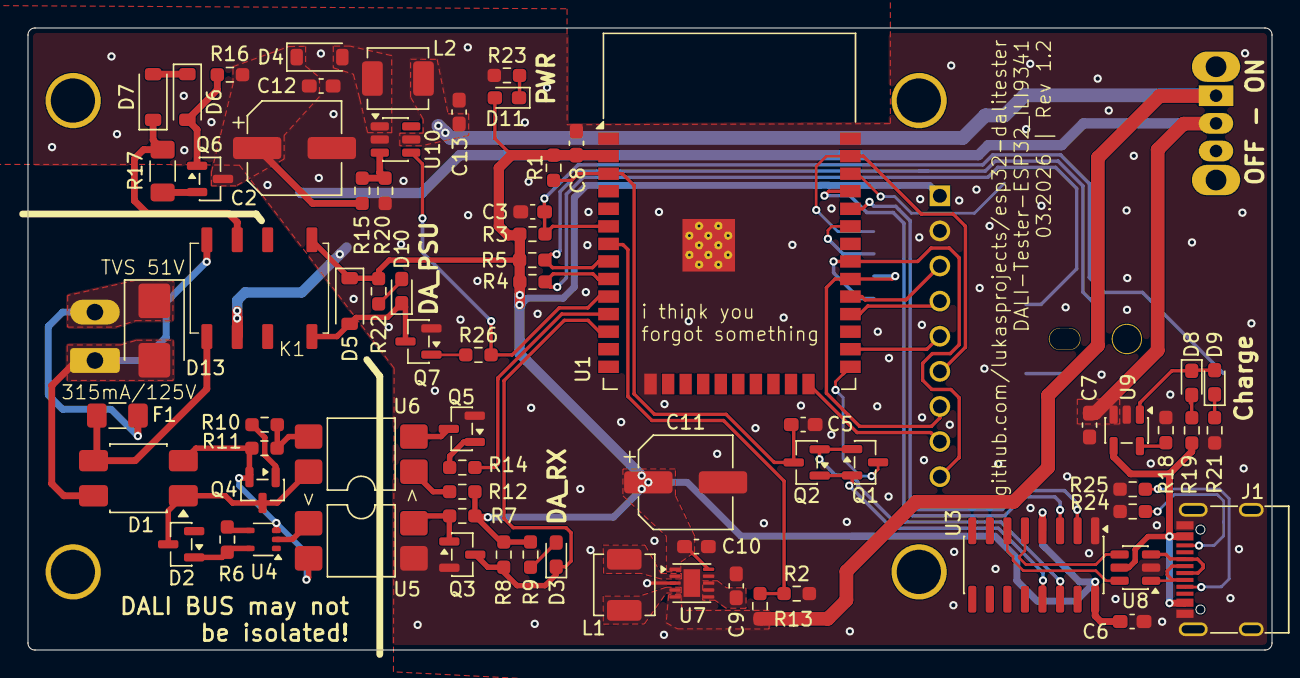
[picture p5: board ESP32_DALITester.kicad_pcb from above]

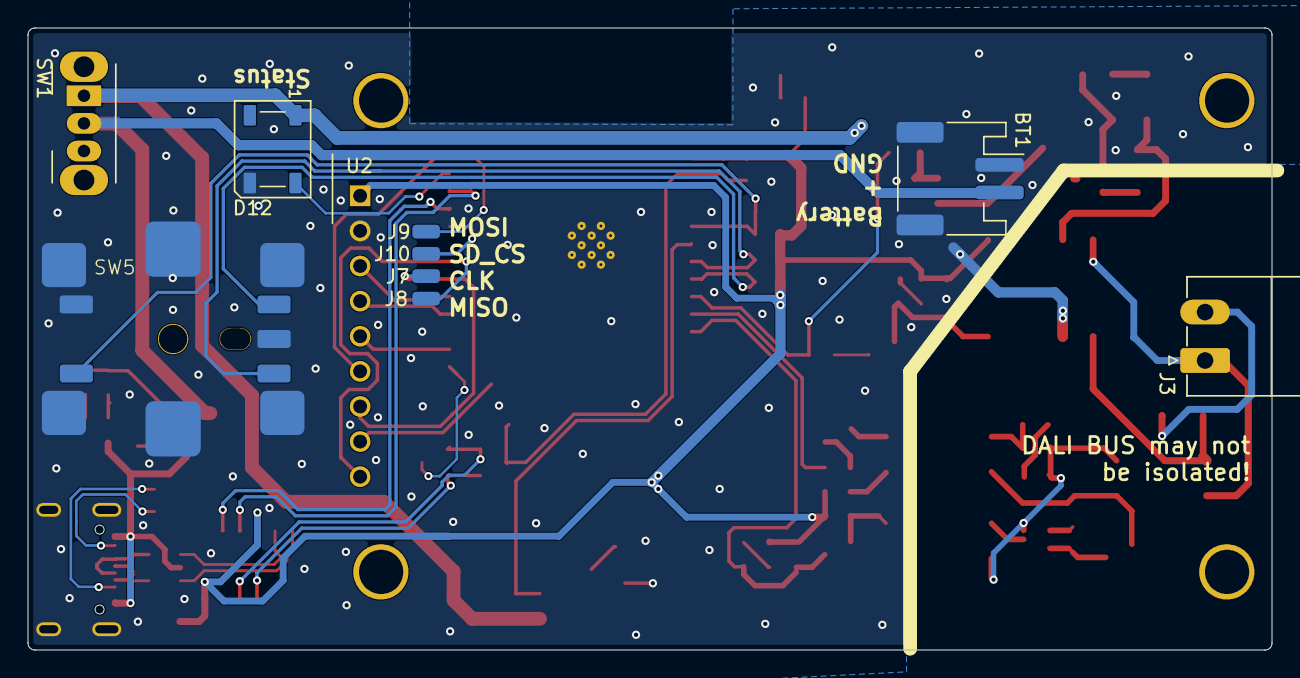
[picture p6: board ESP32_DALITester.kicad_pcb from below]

Board: 2 copper layers, 90.0 x 45.0 mm, 84 parts (10 on the bottom side), 66 nets.

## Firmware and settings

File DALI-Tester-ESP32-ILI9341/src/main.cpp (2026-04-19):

/**
 * @file main.cpp
 * @brief DALI Tester - Main application entry point
 * 
 * ESP32-based DALI bus tester with TFT display and rotary encoder control.
 * Supports DALI Master functionality and Bus Monitoring.
 * 
 * Hardware:
 * - ESP32 DevKit
 * - ILI9341 2.2" TFT Display (SPI)
 * - Rotary Encoder with push button
 * - DALI Interface (TX/RX via optocoupler/transistor)
 * - Optional internal PSU control
 * 
 * See config.h for pin assignments and settings.
 */

#include <Arduino.h>
#include <SPI.h>
#include "config.h"
#include "ui/ui.h"
#include "ui/screens.h"
#include "dali/dali_interface.h"

// =============================================================================
// Forward Declarations
// =============================================================================
void handleInput();
void handleScreenUpdate();

// =============================================================================
// Setup
// =============================================================================
void setup() {
    // Initialize serial for debugging
    Serial.begin(115200);
    Serial.println(F("\n\n================================="));
    Serial.println(F("DALI Tester - ESP32 + ILI9341"));
    Serial.println(F("================================="));
    
    // Initialize SPI
    SPI.begin(TFT_SCLK, TFT_MISO, TFT_MOSI, TFT_CS);
    
    // Initialize UI (display)
    Serial.println(F("Initializing TFT display..."));
    uiInit();
    
    // Show splash screen
    tft.fillScreen(COLOR_BG);
    uiDrawTextCentered(80, "DALI Tester", COLOR_HIGHLIGHT, 2);
    uiDrawTextCentered(120, "ESP32 + ILI9341", COLOR_TEXT, 1);
    uiDrawTextCentered(140, "Initializing...", COLOR_TEXT, 1);
    
    // Initialize encoder
    Serial.println(F("Initializing encoder..."));
    encoderInit();
    
    // Initialize DALI interface
    Serial.println(F("Initializing DALI interface..."));
    daliInit();
    
    // Initialize battery monitoring
    Serial.println(F("Initializing battery monitoring..."));
    batteryInit();
    
    // Short delay to show splash
    delay(1000);
    
    // Clear and draw home screen
    tft.fillScreen(COLOR_BG);
    ui.needsFullRedraw = true;
    
    Serial.println(F("Initialization complete!"));
    Serial.println(F("Ready for operation."));
}

// =============================================================================
// Main Loop
// =============================================================================
void loop() {
    // Update encoder state
    encoderUpdate();
    
    // Easter egg: 8-second hold on home screen launches Pong
    static uint32_t pongHoldStart = 0;
    if (ui.currentScreen == SCREEN_HOME && encoder.btnPressed) {
        if (pongHoldStart == 0) pongHoldStart = millis();
        if ((millis() - pongHoldStart) >= 8000) {
            pongHoldStart = 0;
            memset(&pongState, 0, sizeof(pongState));
            uiSetScreen(SCREEN_PONG);
        }
    } else {
        pongHoldStart = 0;
    }
    
    // Get input events
    int16_t delta = encoderGetDelta();
    ButtonEvent btn = encoderGetButtonEvent();
    
    // Handle input for current screen
    if (delta != 0 || btn != BTN_NONE) {
        if (ui.currentScreen < SCREEN_COUNT) {
            screenHandlers[ui.currentScreen].input(delta, btn);
        }
    }
    
    // Screen-specific updates (e.g., locate toggle, bus monitor)
    if (ui.currentScreen == SCREEN_LOCATE) {
        screenLocateUpdate();
    } else if (ui.currentScreen == SCREEN_BUS_MONITOR) {
        screenBusMonUpdate();
    } else if (ui.currentScreen == SCREEN_SCAN_DEVICE_INFO) {
        screenScanDeviceInfoUpdate();
    } else if (ui.currentScreen == SCREEN_PONG) {
        screenPongUpdate();
    } else {
        // Always check for bus activity (for status badge)
        daliMonitorUpdate();
    }
    
    // Update DALI status (auto-timeout ACT->IDLE)
    daliStatusUpdate();
    
    // Update battery reading
    batteryUpdate();
    
    // Update display
    bool wasFullRedraw = ui.needsFullRedraw;
    if (ui.needsFullRedraw || ui.needsPartialRedraw) {
        if (ui.currentScreen < SCREEN_COUNT) {
            screenHandlers[ui.currentScreen].draw();
        }
        ui.needsPartialRedraw = false;
    }
    
    // Always update status badges (for live status display)
    // Force redraw after full screen redraw
    if (wasFullRedraw) {
        ui.needsFullRedraw = true;  // Temporarily restore for badge
    }
    uiDrawStatusBadge();
    ui.needsFullRedraw = false;
    
    // Small delay to prevent CPU hogging
    delay(5);
}

// =============================================================================
// Debug Helper (optional)
// =============================================================================
#ifdef DEBUG_ENABLED
void debugPrintStatus() {
    static uint32_t lastDebugPrint = 0;
    uint32_t now = millis();
    
    if (now - lastDebugPrint >= 1000) {
        lastDebugPrint = now;
        
        Serial.printf("Screen: %d, Selected: %d, Scroll: %d\n", 
                      ui.currentScreen, ui.selectedIndex, ui.scrollOffset);
        Serial.printf("Encoder: pos=%ld, btn=%d\n", 
                      encoder.position, encoder.btnPressed);
        Serial.printf("DALI Status: %s, PSU: %s\n", 
                      daliStatusToString(daliGetStatus()),
                      daliPsuGet() ? "INT" : "EXT");
    }
}
#endif

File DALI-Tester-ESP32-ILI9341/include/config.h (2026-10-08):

/**
 * @file config.h
 * @brief Hardware pin configuration and settings for DALI Tester
 * 
 * Modify these defines to match your hardware setup.
 */

#ifndef CONFIG_H
#define CONFIG_H

// =============================================================================
// Firmware Version
// =============================================================================
#define FW_VERSION  "1.4.5"
#define HW_VERSION  "1.2"

// =============================================================================
// TFT Display Configuration (ILI9341 2.8" SPI)
// =============================================================================
#define TFT_CS      5           // Chip Select
#define TFT_DC      4           // Data/Command
#define TFT_RST     17          // Reset (-1 if connected to ESP32 EN/RST)
#define TFT_MOSI    23          // SPI MOSI (default ESP32 VSPI)
#define TFT_SCLK    18          // SPI SCLK (default ESP32 VSPI)
#define TFT_MISO    19          // SPI MISO (optional for touch)
#define TFT_LED     2           // Backlight control (HIGH = on)

// Display settings
#define TFT_WIDTH   320
#define TFT_HEIGHT  240
#define TFT_ROTATION 1      // Landscape mode

// =============================================================================
// Rotary Encoder Configuration
// =============================================================================
#define ENC_A       33      // Encoder A signal
#define ENC_B       32      // Encoder B signal
#define ENC_BTN     34      // Encoder push button (active LOW with external pullup)

#define ENCODER_DIR     -1   // Direction: +1 or -1 to reverse
#define ENC_STEP_DIV    4   // Steps per detent (typical: 4 for most encoders)

// Button timing
#define BTN_DEBOUNCE_MS     50      // Debounce time in ms
#define LONG_PRESS_MS       700     // Long press threshold in ms

// =============================================================================
// DALI Interface Configuration
// =============================================================================
#define DALI_TX     26      // DALI transmit pin
#define DALI_RX     27      // DALI receive pin

// TX/RX inversion settings (depends on your optocoupler/transistor circuit)
// For Waveshare Pico-DALI2: Try both polarities if one doesn't work
#define DALI_TX_INVERT  true    // true = TX HIGH pulls bus LOW (matches working reference firmware)
#define DALI_RX_INVERT  false   // false for Waveshare Pico-DALI2

// =============================================================================
// DALI PSU Control
// =============================================================================
#define DALI_PSU_EN         25      // PSU enable pin
#define PSU_EN_ACTIVE_HIGH  true    // true if HIGH enables PSU

// =============================================================================
// UI Configuration
// =============================================================================
#define HEADER_HEIGHT       32      // Header bar height in pixels (larger for better badge visibility)
#define FOOTER_HEIGHT       20      // Footer bar height in pixels
#define CONTENT_TEXT_SIZE   2       // Text size for content area (1=6x8, 2=12x16)
#define MENU_ITEM_HEIGHT    24      // Height per menu item (adjust for text size)

// Colors (RGB565)
#define COLOR_BG            0x0000  // Black background
#define COLOR_TEXT          0xFFFF  // White text
#define COLOR_HEADER_BG     0x001F  // Blue header
#define COLOR_FOOTER_BG     0x0010  // Dark blue footer
#define COLOR_PROJECT_HEADER_BG 0xA800  // Dark red header in loaded project mode
#define COLOR_PROJECT_FOOTER_BG 0x5800  // Dark red footer in loaded project mode
#define COLOR_HIGHLIGHT     0x07E0  // Green highlight
#define COLOR_SELECTED      0x07FF  // Cyan selection
#define COLOR_WARNING       0xFBE0  // Orange warning
#define COLOR_ERROR         0xF800  // Red error
#define COLOR_SUCCESS       0x07E0  // Green success
#define COLOR_BADGE_IDLE    0x4208  // Gray badge
#define COLOR_BADGE_ACT     0x07E0  // Green - activity
#define COLOR_BADGE_SEND    0xFFE0  // Yellow - sending
#define COLOR_BADGE_ERR     0xF800  // Red - error

// =============================================================================
// Bus Monitor Configuration
// =============================================================================
#define BUSMON_MAX_ENTRIES  80      // Ring buffer size for bus monitor
#define BUSMON_REFRESH_MS   80      // Max refresh rate (~12fps)

// =============================================================================
// Locate Function
// =============================================================================
#define LOCATE_INTERVAL_MIN     200     // Minimum interval in ms
#define LOCATE_INTERVAL_MAX     3000    // Maximum interval in ms
#define LOCATE_INTERVAL_STEP    100     // Step size in ms
#define LOCATE_INTERVAL_DEFAULT 1000     // Default interval
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

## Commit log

2026-02-25 Initial README for ESP32 DALI Tester project
    Add detailed project description, features, hardware, and usage instructions for the ESP32 DALI Tester.
2026-04-19 Delete KiCAD/ESP32_DALITester directory
    Old Version
    [ESP32_DALITester-B_Cu.gbr, ESP32_DALITester-B_Mask.gbr, ESP32_DALITester-B_Paste.gbr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]
2026-04-19 Add files via upload
    Rev1.2, tested and working, but DALI voltage around 15V
    [ESP32_DALITester-B_Cu.gbr, ESP32_DALITester-B_Mask.gbr, ESP32_DALITester-B_Paste.gbr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]
2026-04-19 Add files via upload
    Rev1_2 Gerber, bugfixes at DALI powersupply
2026-04-19 Add files via upload
    PCB Renders
2026-10-08 sd card if and WAGO DALI Configurator Files
    New FW 1.4.5
    possible to Interface SD card slot. Open, change (live in ballasts and the files) and save WAGO Dali Configurator files (they can be reopened with the Wago tool).
